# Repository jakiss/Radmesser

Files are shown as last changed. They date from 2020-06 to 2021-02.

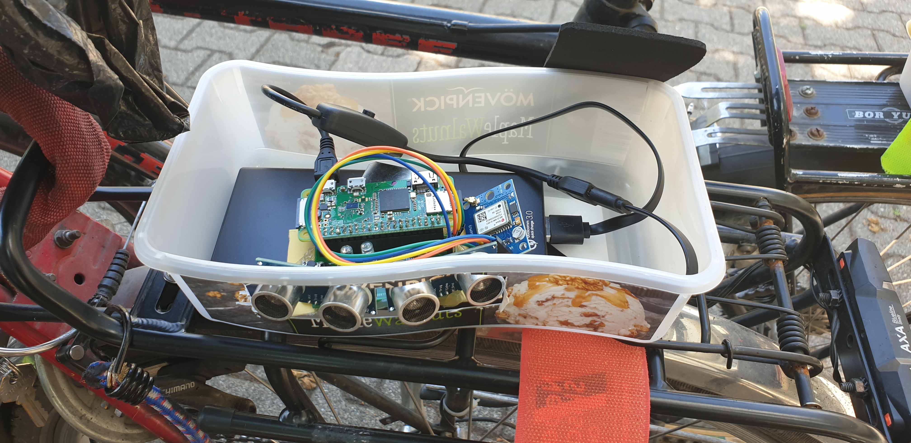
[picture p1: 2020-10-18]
Anleitung_v01_20201018/Bilder/20200816_124822.jpg

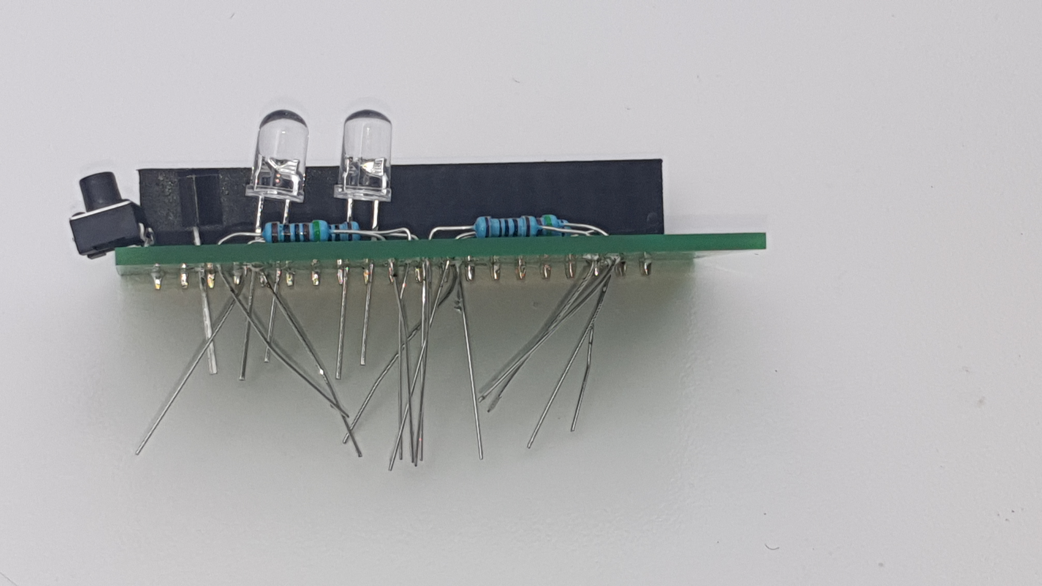
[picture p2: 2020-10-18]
Anleitung_v01_20201018/Bilder/20200725_165101.jpg

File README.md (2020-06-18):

# Radmesser
For the enlish version see below.

Das Projekt befasst sich mit der Entwicklung eines Radmessers nach der Idee des Tagesspiegel Berlin (Vgl. https://interaktiv.tagesspiegel.de/radmesser/ und https://github.com/tagesspiegel/radmesser). 

Die genaue des Beschreibung des Projekts mit Grundidee und Annahmen findet sich unter Projektbeschreibung.pdf, um eine kurze Zusammenfassung zu erhalten empfiehlt sich die Datei Zusammenfassung_Projektbeschreibung.pdf.

Das Projekt darf unter der GNU General Public License (GPL) verwendet werden.

------------------------------------------------------------
English version:

The project deals with the development of a measurement system for the overtaking distance between cars and bicycles after the idea of the Tagesspeigel Berlin (see https://interaktiv.tagesspiegel.de/radmesser/ and https://github.com/tagesspiegel/radmesser).

The detailed description of the project including the main idea and assumptions  can be found in Projektbeschreibung.pdf. For a short summary of the topic the file Zusammenfassung_Projektbeschreibung.pdf is recommended.

The project can be reused under the GNU General Public License (GPL).

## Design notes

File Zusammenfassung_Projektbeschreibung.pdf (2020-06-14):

(T3 3000) – Jahrgang 2017

MESSSYSTEM ZUR BESTIMMUNG VON UBERHOLABST ¨ | ANDEN ¨

## VON KRAFTFAHRZEUGEN GEGENUBER FAHRRADFAHRERN ¨

Jakob Seitzer
Elektrotechnik, TEL17GR5, DHBW Stuttgart
Kurzfassung: Die Arbeit beschaftigt sich mit der Entwicklung eines Messsystems zur Ermittlung der ¨ | Uberhol- ¨
abstande von Kraftfahrzeugen gegen ¨ | uber Fahrradfahrern. Zur Bestimmung der seitlichen Abst ¨ | ande werden Ul- ¨
traschallsensoren (HC-SR04) verwendet, welche an einem Raspberry Pi Zero angebunden sind. Ein Temperatursensor (DS18B20) wird zur Kompensation der Temperaturabhangigkeit der Abstandsmessung verwendet. ¨ Das GPS-Modul GY-GPS6MV2 wird zur Bestimmung von Zeit und Position verwendet. Mit Hilfe einer Auswer-
tungssoftware werden Uberholvorg ¨ | ange aus den aufgezeichneten Daten extrahiert. ¨
Sch ¨usselworter: ¨ | Uberholabstand, Abstandsmessung, Ultraschallsensoren, HC-SR04, GPS-Modul ¨

Abstract: This student research project deals with the construction of a measurement system for recording overtakindg distances between motor wehicels and byciles. For measuring the distance on the left side of the bycile, two ultrasonic ranging sensors (HC-SR04) are used and connected to a Raspberry Pi Zero. A temperature sensor (DS18B20) is used for compensation of tempreature dependency of the distance measurement. The GPS-receiver GY-GPS6MV2 is used for detection of position and time. With a evaluation software the overtaking actions are detectet in the measured data.

Keywords: overtaking distance, distance measurement, ultra sonic raning module, HC-SR04, GPS-receiver

### 1 EINFUHRUNG ¨

Am 28.04.2020 trat die aktuell letzte Anderung der Straßenverkehrsordnung in Kraft. Zentrale Anpassung stellte ¨
hierbei die genaue Festlegung des Mindestuberholabstandes von Kraftfahrzeugen gegen ¨ | uber Fahrradfahrern ¨
dar. Innerorts muss beim Uberholen ein seitlicher Abstand von mindestens ¨ | | | 1,5 m eingehalten werden - außerorts
mindestens 2 m.
In einer groß angelegten Studie des Tagesspiegel Berlin aus dem Jahr 2018, wurde versucht die Uberholabst ¨ | ande ¨
gegenuber Fahrradfahrern in Berlin zu dokumentieren [ ¨ | 1]. Der entwickelte Radmesser ist nicht frei verfugbar. ¨
Aus diesem Grund konnen die Daten nicht unabh ¨ | angig gepr ¨ | uft werden. Es bestehen noch weitere Konzepte ¨
zur Konstruktion eines Radmessers, diese sind jedoch nicht vollstandig funktionsf ¨ | ahig [ ¨ | 2]. Um die Ergebnisse
der Studie des Tagesspiegels zu uberpr ¨ | ufen und auch Daten ¨ | uber andere St ¨ | adte zu erhalten, soll ein offenes ¨
Messsystem zu Erfassung der Uberholabst ¨ | ande entwickelt werden. ¨

### 2 SYSTEMBESCHREIBUNG

Fur das Erfassen der ¨ | Uberholabst ¨ | ande wird ein Messsystem entwickelt werden, welches am Fahrrad montiert ¨
wird und automatisch die Abstande nach links aufzeichnet. Mit Hilfe einer Software werden anschließend die ¨
Uberholabst ¨ | ande aus den gewonnenen Daten extrahiert. ¨

### 2.1 Hardwarekomponenten

Als zentrales Hardwareelement wird eine Recheneinheit benotigt, welche mit den Abstandssensoren kommu- ¨ nizieren kann. Um eine unabhangige und einfache Funktionsweise zu erreichen, wird mit dem Raspberry Pi ¨
Zero gearbeitet. Dieser stellt 40 GPIO-Pins zur Verfugung, an welche Sensoren angeschlossen werden k ¨ | onnen. ¨
Mit der Sprache Python 3 wird eine Software fur das Messsystem auf dem Raspberry Pi entwickelt. Auf der ¨ Micro-SD-Karte des Raspberry Pis werden die gemessenen Daten gespeichert werden.

Um den Uberholabstand zu erfassen werden zwei Ultraschallsensoren verbaut. Als Standardbauteil im unteren ¨
Preissegment fur Abstandssensoren bietet sich der Ultraschallsensor HC-SR04 an. Dieser erfasst zuverl ¨ | assig ¨
einen Messbereich zwischen 4 cm und 5 m und wird in vielen studentischen Projekten verwendet [3] [4]. Die Messung erfolgt nach einem Triggerimpuls von 10 µs. Es werden Schallwellen mit einer Frequenz von 40 kHz
ausgesendet und der Ruckmelde-Pin des Sensors geht auf ¨ | High. Wird der ausgegeben Schall innerhalb von

38 ms wieder empfangen, geht der Ruckmelde-Pin zum Empfangszeitpunkt wieder auf ¨ | Low, ansonsten nach
tmax = 38 ms.

Bei der Verwendung eines Ultraschallsensors muss die Temperaturabhangigkeit der Schallgeschwindigkeit be- ¨
rucksichtigt werden. Im Einsatzbereich des Messsystems ist mit Temperaturen zwischen ¨ | −10 °C und 35 °C, was
eine Abweichung der Schallgeschwindigkeit von bis zu 10 % zur Folge hat. Um die Temperaturabhangigkeit ¨ auszugleichen, wird die Temperatur mit dem Temperatursensor DS18B20 bestimmt. Dieser zeichnet sich durch
einen gunstigen Preis und eine weite Verbreitung in anderen Projekten aus [ ¨ | 5] [6].
Bei dem GPS-Modul, welches fur die Positions- und Zeitbestimmung ben ¨ | otigt wird, gibt es kaum etablierte ¨
Bauteile. Nach ausfuhrlicher Recherche fiel die Entscheidung auf das GPS-Modul NEO-6 der Firma u-blox. F ¨ | ur¨
die vereinfachte Konnektivitat hin zum Raspberry Pi Zero wird das Modul GY-GPS6MV2 verwendet, auf welchem ¨
der Chip NEO-6 verbaut ist. Dieses Modul ist kostengunstig erh ¨ | altlich und kann ¨ | uber die Universal Asynchronous ¨
Receiver Transmitter-Schnittstelle (UART) mit dem Raspberry verbunden werden [7].
Die Uberholvorg ¨ | ange werden durch die unterschiedlichen Zeitpunkte bestimmt, zu welchen das Kraftfahrzeug ¨
von den beiden Ultraschallsensoren erfasst wird. Um eine zeitlich unterschiedliche Erfassung durch die Ultraschallsensoren zu erreichen, mussen diese entweder in einem ausreichenden Abstand voneinander ent- ¨ fernt montiert sein, oder in zwei unterschiedliche Richtungen messen. Zuerst muss in diesem Zusammenhang bestimmt werden, welche maximale Distanz lmax ein Kraftfahrzeug zwischen zwei Messungen der Ul-
traschallsensoren zurucklegt. Innerhalb von St ¨ | adten ist mit einer maximalen Geschwindigkeitsdifferenz von ¨
vmax = 70 km h⁻¹ ≈ 19,44 m s⁻¹ zwischen Radfahrer und Kraftfahrzeug beim Uberholen zu rechnen. ¨
lmax = vmax · tmax = 0,038 ms · 19,44 m s⁻¹ = 0,739 m | (1)
Die Montage der beiden Ultraschallsensoren ist nicht in einem Abstand von 70 cm moglich, da der zur Verf ¨ | ugung ¨
stehende Platz auf dem Fahrrad begrenzt ist. Deshalb mussen die Ultraschallsensoren in zwei unterschiedliche ¨ Richtungen messen. Der minimale Winkel αmin, welchen die Ultraschallsensoren voneinander abgewandt sein
mussen, wird mit Hilfe der berechneten Strecke ¨ | lmax und einer angenommenen Messdistanz von lMess = 1,5 m
bestimmt. Es gilt die Annahme, dass bei α = 0° die Ultraschallsensoren das Kraftfahrzeug zeitgleich erkennen.

αmin = arctan

lmax

lMess

=

0,739 m
1,5 m
= 26,23° | (2)
Es besteht die Moglichkeit entweder einen Ultraschallsensor um mindestens ¨ | αmin = 26,33° vom anderen abzu-
wenden, oder beide um mindestens αmin/2 = 13,17° gegeneinander zu verstellen. Um genauere Messergebnisse zu erzielen, werden beide Ultraschallsensoren um αmin/2 verdreht. Bei dieser Montageart ist der Winkel zwischen Ultraschallsensor und Kraftfahrzeug geringer und die Messabweichung fallt geringer aus. ¨
Alle benotigten Bauteile werden auf eine in KiCad entwickelten Leiterplatte gel ¨ | otet. Dies bietet sowohl die ¨
Moglichkeit einer dauerhaften und sicheren Montage, als auch eine exakte Positionierung der Ultraschallsen- ¨
soren bezuglich des Winkels ¨ | α.

### 2.2 Software f ¨ur das Messsystem

Wie bereits oben beschrieben, kann auf dem Raspberry Pi ein Programm in Python 3 entwickelt werden. Drei zentrale Anforderungen muss das Programm erfullen: ¨

1. Moglichst viele Abstandsmessungen ¨
2. Hohe Ausfallsicherheit
3. Hohe Datensicherheit
Moglichst viele Messungen ¨ | mit den Ultraschallsensoren sorgen fur eine solide Datenlage. Hierf ¨ | ur werden ¨
die beiden Ultraschallsensoren durch den selben Impuls getriggert, sie starten zeitgleich ihre Messungen.
Die Ruckmelde-Pins werden durch die Software ¨ | uberwacht. Sobald einer der beiden Pins auf ¨ | High ist, wird
dieser Zeitpunkt als Startzeitpunkt fur den Ultraschallsensor verwendet. Befinden sich beide R ¨ | uckmelde-Pins ¨
im High-Zustand, wird uberwacht, wie lange sie in diesem Zustand verbleiben. F ¨ | allt ein R ¨ | uckmelde-Pin wie- ¨
der auf Low, ist dessen Messung beendet und die Zeit tMess, kann zusammen mit der Schallgeschwindigkeit cSchall = 340 m s⁻¹ zur Ermittlung der Messdistanz verwendet werden. Unter Berucksichtigung, dass der Schall ¨
in der Zeit tmess sowohl Hin- als Ruckweg zum Kraftfahrzeug zur ¨ | uck gelegt hat, bestimmt sich die Entfernung ¨
des KFZ lMess zu

lMess =

1
- tMess · cSchall | (3)

Sobald beide Ultraschallsensoren ihre Messung beendet haben und das Messergebnis in einer CSV-Datei gespeichert wurde, wird unmittelbar im Anschluss wieder eine neue Messung initiiert. Das Erfassen der Zeit und Postion ist weniger oft notwendig, da zwischen zwei erfassten Positionen interpoliert werden kann, solange diese nicht zu weit voneinander entfernt sind. Als maximaler zeitlicher Abstand tGP Smax ergibt sich aus einem
maximalen raumlichen Abstand, bei welchem noch interpoliert werden kann, von ¨ | lGP Smax = 20 m und einer
maximalen Geschwindigkeit des Fahrradfahrers von vbikemax = 30 km h⁻¹ = 8,33 m s⁻¹
| :

tGP Smax =

lGP Smax

vbikemax

| | = 2,4 s | (4)

Die Temperaturmessung nimmt eine Zeit von bis zu 750 ms in Anspruch [6] und wird deshalb nur in Minuten-
abstanden durchgef ¨ | uhrt. Eine starke Temperaturschwankung ist w ¨ | ahrend einer Fahrradfahrt nicht zu erwarten, ¨
jedoch zwischen verschiedenen Fahrten. Um den Speicherverbrauch moglichst gering zu halten, wird drauf ¨ verzichtet die Postions- und Temperaturdaten zu jedem Messwert der Ultraschallsensoren hinzuzufugen. Diese ¨ werden lediglich einmal als eigene Zeile zum Zeitpunkt der Messung abgelegt.
Ein Eingriff in das Messsystem ist wahrend des Betriebs nicht m ¨ | | oglich und macht deshalb eine ¨ | hohe Ausfallsi-
cherheit erforderlich. Daten mussen zuverl ¨ | assig aufgezeichnet werden. Aus diesem Grund ist ein Stehenbleiben ¨
oder Abbruch des Programms zu verhindern. Durch das sofortige und standige Wiederholen der Messungen ¨ mit den Ultraschallsensoren besteht die Gefahr, dass nicht alle Messungen reibungslos Ablaufen. Wird ein Triggerimpulses nicht korrekt erkannt, wird der normale Messzyklus durchbrochen. Durch Uberwachung der Zeit, ¨
welche das Programm fur eine Abstandsmessung ben ¨ | otigt, wird beim ¨ | Uberschreiten einer Zeitgrenze von ¨ | 50 ms
die Messung beendet. Zudem wird dem Benutzer durch eine Betriebsstatusanzeige bestehend aus zwei LEDs signalisiert, ob ein reibungsloser Programmdurchlauf gewahrleistet ist. Zu Programmstart werden die einzelnen ¨ Komponenten getestet, bevor die Statusanzeige auf betriebsbereit (grune LED) wechselt. Wird ein Sensor als ¨ fehlend oder fehlerhaft erkannt, wird dies dem Nutzer durch eine rote LED signalisiert. Eine Problembehebung muss im Einzelfall erfolgen.

Wahrend einer Messfahrt sind verschiedene Szenarien denkbar, welche zu einem Absturz des Raspberry Pis ¨
fuhren k ¨ | onnen und nicht softwaretechnisch abgefangen werden k ¨ | onnen. Ein Spannungsausfall, entweder durch ¨
eine leere Powerbank oder das Herausrutschen eines Kabels sind ebenso denkbar, wie ein Unfall und eine damit einhergehende Beschadigung des Messsystems bzw. der Recheneinheit. Um die bis zu diesem Zeitpunkt ¨ erfassten Daten nicht zu verlieren, ist eine hohe Datensicherheit erforderlich. In diesem Zusammenhang ist zu berucksichtigen, dass die Datei, welche zum Zeitpunkt des Programmabsturzes beschrieben wird, unbrauchbar ¨ wird und alle darin enthaltenen Daten verloren gehen. Um den Datenverlust zu minimieren, wird nach einer festgelegten Zahl an Messungen (5000) die bisherige Datei geschlossen und eine neue Datei mit fortlaufender Nummerierung erstellt, in welche die neuen Daten gespeichert werden. So gehen maximal 5000 Messwerte verloren, das bedeutet die Messwerte von maximal zwei Minuten.

### 2.3 Auswertungssoftware f ¨ur die Messdaten

Als Auswertungsgrundlage dienen die durch die Messsoftware erstellten CSV-Dateien, welche die gemessenen Abstandswerte, Positionen und Temperaturen beinhalten. Nach dem anfanglichen Einlesen der gemessenen ¨ Daten, welches das Zuweisen der Positions- und Temperaturdaten zu den Abstandsmesswerten beinhaltet, so-
wie die Glattung der gemessenen Abst ¨ | ande, werden diese auf ¨ | Uberholvorg ¨ | ange untersucht. Kennzeichnend ¨
fur¨ Uberholvorg ¨ | ange ist ein Abfallen des Messwerts des hinteren Ultraschallsensors, w ¨ | ahrend der vordere Ul- ¨
traschallsensor weiterhin eine große Distanz erfasst. Danach ermitteln beide Ultraschallsensoren den gleichen kleinen Abstandswert, da sich das Kraftfahrzeug genau neben dem Fahrrad befindet und von beiden Ultraschallsensoren erfasst wird. Zum Ende des Uberholvorgangs steigt der Messwert des hinteren Ultraschallsensors an, ¨ wohingegen der vordere Ultraschallsensor weiterhin das Kraftfahrzeug erfasst und einen kleinen Messwert liefert.
Da jedem Uberholvorgang GPS-Koordinaten zugeordnet sind, ist eine Analyse der ¨ | Uberholvorg ¨ | ange nach Re- ¨
gionen moglich. Um eine exakte regionale Analyse zu erhalten werden die Koordinaten in Adressen bestehend ¨ aus Stadt, Postleitzahl und Straße umgewandelt. Anhand dieser Informationen kann ein Vergleich zwischen
verschiedenen Stadten erfolgen. Innerhalb einzelner St ¨ | adte k ¨ | onnen besonders gef ¨ | ahrliche Straßenabschnitte ¨
erkannt werden. Um die GPS-Koordinaten in Adressen umzuwandeln wird eine Programmierschnittstelle ver-
wendet (Application Programming Interface - API). Aus Kosten- und Kompatibilitatsgr ¨ | unden wird mit der API von ¨
OpencageGeocoder gearbeitet. Nach Ubergabe der Koordinaten wird die dazugeh ¨ | orige Straße gesucht und ¨
die gefundene Adresse mit Informationen uber die Straße (Straßentyp, erlaubte Geschwindigkeit, Anzahl der ¨
Fahrspuren) zuruckgegeben [ ¨ | 8].

### 3 TESTS

### 3.1 Hardwaretests

HC-SR04

la=Messdistanz

lb=seitliche Abweichung

# lc=gemessene Distanz

β

Abbildung 1: Messbereich | der | Ultraschallsensoren
HC-SR04, in Farbe die eingesetzten Objekte

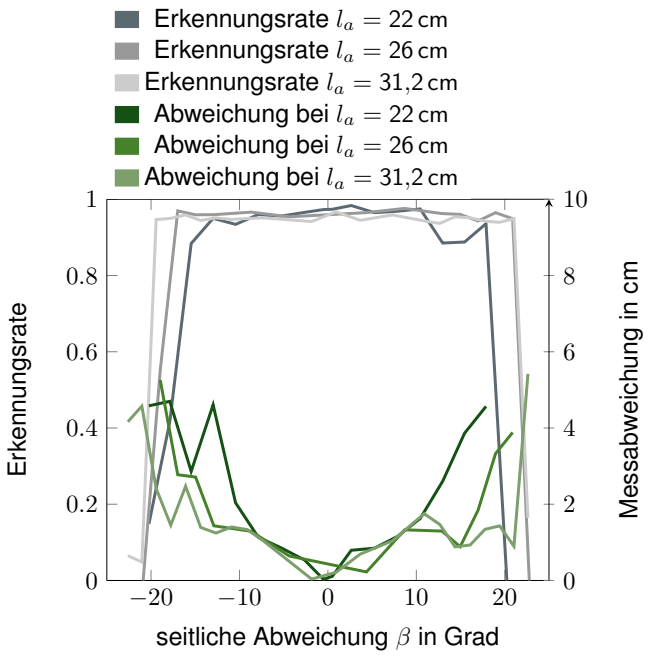
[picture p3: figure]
seitliche Abweichung β in Grad; Erkennungsrate; Messabweichung in cm; Erkennungsrate la = 22 cm Erkennungsrate la = 26 cm Erkennungsrate la = 31,2 cm Abweichung bei la = 22 cm Abweichung bei la = 26 cm Abweichung bei la = 31,2 cm

Abbildung 2: Messbereich der Ultraschallsensoren bei verschiedenen la

Die Ultraschallsensoren mussen hinsichtlich ihres Messbereichs untersucht werden. Durch Tests muss nachge- ¨ wiesen werden, dass die Ultraschallsensoren auch Objekte erfassen, welche nicht senkrecht vor den Ultraschall-
sensoren stehen. In diesem Zusammenhang wird untersucht, inwiefern eine schrage Messfl ¨ | ache (Vgl. Abb. ¨ | 3)
die Messungen beeinflusst und welchen Einfluss ein Abweichen aus der Messsenkrechten (Vgl. Abb. 1) auf die Messergebnisse hat.

In Abb. 1 ist die seitliche Abweichungen eines Objekts von der Messsenkrechten dargestellt. Der Winkel β stellt den Messbereich dar und berechnet sich zu

β = arctan
lb
la
(5)
In Abb. 2 ist die Erkennungsrate in Abhangigkeit der seitlichen Abweichung ¨ | β dargestellt. Die Erkennungsrate ist
definiert als Anteil der Messungen, bei welcher das Objekt erkannt wird. Die Messabweichung ergibt sich aus der
tatsachlich gemessenen Distanz abz ¨ | uglich ¨ | lc. Fur die in Abb. ¨ | 2 dargestellten Punkte, wurden jeweils mindestens
40 000 Messungen durchgefuhrt und per Software ausgewertet. Bei steigender Messdistanz ¨ | la vergroßert sich ¨
der Messbereich β leicht. Zu beobachten ist, dass bis zu einem Winkel β von bis zu 19° ein Objekt zuverlassig ¨ erkannt wird. Die Messabweichung steigt bereits bei β > 16° stark an.
In Abb. 3 ist der Versuchsaufbau fur eine schr ¨ | age Messfl ¨ | ache skizziert. Der Winkel ¨ | γ stellt die Schrage der ¨
Messflache gegen ¨ | uber einer normalen Messfl ¨ | ache, senkrecht zur Messrichtung der Ultraschallsensoren dar. In ¨
Abb. 4 sind die Erkennungsrate und die Messabweichung fur variable Messdistanzen ¨ | la in Abhangigkeit des ¨
Winkels γ dargestellt. Es gelten die selben Definitionen wie oben. Bei steigender Messdistanz la verkleinert sich die Erkennungsrate bei einem Winkel von β ≥ 30° leicht. Die Messabweichung steigt ebenfalls mit zunehmender Schrage ¨ γ der Messflache an. ¨

Das Zunehmen der Messabweichung ist mit dem Erkennungswinkel β der Ultraschallsensoren zu begrunden. ¨
Wird die Messflache mit dem Winkel ¨ | γ schrager aufgestellt, r ¨ | uckt ein Teil der Messfl ¨ | ache innerhalb des Erken- ¨
nungsbereichs naher an den Ultraschallsensor (Vgl. Abb. ¨ | 3, grau gestrichelter Bereich).

HC-SR04

la=Messdistanz

γ

Abbildung 3: Messgenauigkeit bei schragen Fl ¨ | achen, ¨
in Farbe die neuen Messflachen ¨

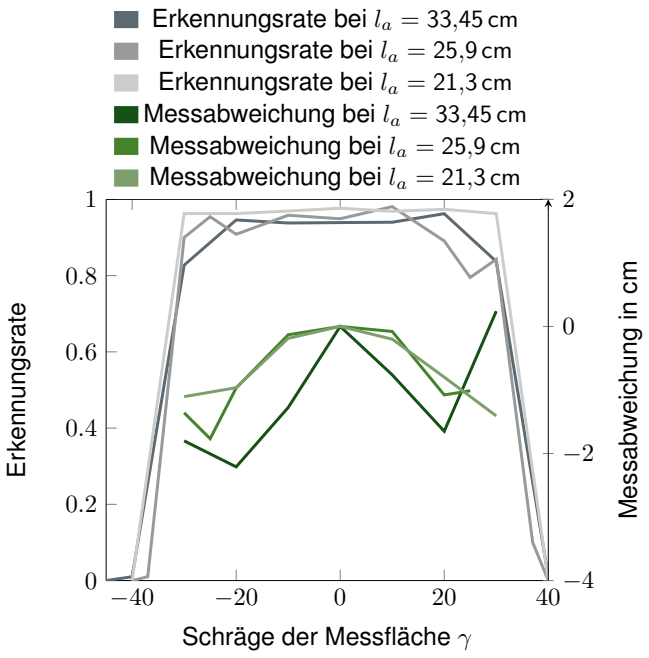
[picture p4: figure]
Schrage der Messfl ¨; ache ¨; Erkennungsrate; Messabweichung in cm; Erkennungsrate bei la = 33,45 cm Erkennungsrate bei la = 25,9 cm Erkennungsrate bei la = 21,3 cm Messabweichung bei la = 33,45 cm Messabweichung bei la = 25,9 cm Messabweichung bei la = 21,3 cm

Abbildung 4: Genauigkeit der Messungen mit Ultraschallsensoren bei schragen Reflexions- ¨ flachen ¨

Es ist festzuhalten, dass die Ultraschallsensoren Objekte erkennen konnen, welche bis zu ¨ | β = 19° aus der
Messsenkrechten abweichen. Die Schrage der Messfl ¨ | ache spielt bei ¨ | γ ≤ 19° eine untergeordnete Rolle. Fur eine ¨
zuverlassige Objekterkennung mit vernachl ¨ | assigbaren Messabweichungen muss der Winkel ¨ | α/2 (Vgl. oben)
kleiner als der Winkel β des Messbereichs sein. Es gilt:

αmax
2
≤ β = 19° | (6)

Bei verschiedenen Tests stellte sich ein Winkel von α/2 = 16° als optimal heraus.

### 3.2 Softwaretest Messsystem

Fur das Messsystem ist ein stabiler Programmablauf sowie das Behandeln von fehlerbehafteten Messwerten ¨
und Sensorausfallen wichtig. Ein Fortlauf des Programms sowie eine nachtr ¨ | agliche Bearbeitungsm ¨ | oglichkeit f ¨ | ur¨
fehlerhafte Messergebnisse stehen im Vordergrund.

In diesem Zusammenhang ist ein Langzeittest erforderlich, um Fehler zu erkennen, welche nicht bereits bei
Programmstart auftreten. Unabhangig der Programmlaufzeit sind keine zus ¨ | atzlichen Fehler aufgetreten. Nach ¨
rund 20 Stunden ist die Powerbank, welche zur Spannungsversorgung verwendet wird, erschopft. ¨

Beim GPS-Modul sind zwei unterschiedliche Fehler moglich. Es kann zu einem kurzfristigen Signalabbruch ¨ kommen oder zu einem dauerhaften Komplettausfall. In beiden Fallen wird der Programmablauf nicht negativ ¨ beeinflusst. Sind die GPS-Daten nur kurzfristig nicht verfugbar, kann zwischen den anderen Koordinaten in- ¨
terpoliert werden. Bei einem dauerhaften Sensorausfall hingegen ist es nicht mehr moglich ¨ | Uberholvorg ¨ | ange ¨
geografisch zu verorten.

Die Ultraschallsensoren konnen verschiedene Fehler aufweisen. Bei einzelnen Messungen kann es zu falschen ¨
Messergebnissen kommen, die Ultraschallsensoren konnen verdeckt oder verschmutzt sein oder sie k ¨ | onnen ¨
komplett ausfallen. Das Programm des Messsystems wird nicht durch falsche Signale der Ultraschallsensoren beeinflusst, da durch einen Zeitabgleich auch ohne Rucksignal der Ultraschallsensoren mit neuen Messungen ¨ fortgefahren wird. Fehlerhafte Messergebnisse, welche außerhalb des Messbereichs der Ultraschallsensoren
liegen konnen durch die Auswertungssoftware aussortiert werden und einzelne abweichende Messwerte k ¨ | onnen ¨
durch die Auswertungssoftware korrigiert werden (Vgl. Glattung). Ein Komplettausfall eines Ultraschallsensors ¨
fuhrt zu einem fatalen Fehler bei der Erkennungssoftware, da diese zur Erkennung von ¨ | Uberholvorg ¨ | angen auf ¨
die unterschiedlichen Messergebnisse der Ultraschallsensoren angewiesen ist.

### 3.3 Softwaretest Auswertungssoftware

Die Auswertungssoftware wird mit gezielt durchgefuhrten ¨ | Uberholvorg ¨ | angen getestet. Die ¨ | Uberholvorg ¨ | ange ¨
wurden mit einem moglichst exakten seitlichen Abstand durchgef ¨ | uhrt, aufgrund von Lenkfehlern von Autofahrer ¨
und Fahrradfahrer, konnte die Distanz jedoch nicht exakt eingehalten werden. Die Auswertungssoftware er-
kannte die Uberholvorg ¨ | ange aus den aufgezeichneten Daten, kleine Abweichungen waren bei der ermittelten ¨
Distanzen zu erkennen. An Stellen ohne Uberholvorg ¨ | ange wurden keine ¨ | Uberholvorg ¨ | ange extrahiert. Die Funk- ¨
tion der Software wurde somit fur beide Richtungen nachgewiesen, korrektes Erkennen aber keine zu große ¨ Sensitivitat. ¨

### 4 FAZIT

Es wurde ein Messsystem zur Erfassung der seitlichen Uberholabst ¨ | ande von Kraftfahrzeugen gegen ¨ | uber Fahr- ¨
radfahrern entwickelt. Uberholvorg ¨ | ange werden durch die Auswertungssoftware automatisch erkannt und regio- ¨
nal verortet. Die Funktion des Messsystems wurde durch mehreren Testreihen nachgewiesen.

Weitere Tests mit verschiedenen Arten von Kraftfahrzeugen sind notwendig, genauso wie das Testen der Aus-
wertungsmoglichkeiten, sobald Daten ¨ | uber viele ¨ | Uberholvorg ¨ | ange vorliegen. ¨

LITERATUR

[1] Tagesspiegel Online. (2018). “radmesser”, Verlag Der Tagesspiegel GmbH, Adresse: https://interaktiv.tagesspiegel.de/radmesser/index.html (https://interaktiv.tagesspiegel.de/radmesser/index.html) (besucht am 12. 12. 2019).
[2] Zweirat Stuttgart. (2020). “Friends of Open Bike Sensor, Citizen Science Project by Zweirat Stuttgart”, Adresse: https://github.com/Friends-of-OpenBikeSensor (besucht am 28. 05. 2020).
[3] K. A. Raza und W. Monnet, “Moving objects detection and direction-finding with HC-SR04 ultrasonic linear array”, in 2019 International Engineering Conference (IEC), 2019, S. 153–158.
[4] D. Vakula und Y. K. Kolli, “Low cost smart parking system for smart cities”, in 2017 International Conference on Intelligent Sustainable Systems (ICISS), 2017, S. 280–284.
[5] W. Jingzhuo und G. Chenglong, “Research on 1-Wire Bus Temperature Monitoring System”, in 2007 8th International Conference on Electronic Measurement and Instruments, 2007, S. 3–722–3–726.
[6] B. Huang, J. Lei und Y. Bo, “The reading data error analysis of 1-wire bus digital temperature sensor DS18B20”, in 2012 Proceedings of International Conference on Modelling, Identification and Control, Wuhan, Hubei, China, Juni 2012, S. 433–436, ISBN: 978-1-4673-1524-1.
[7] H. Fu, G. Xiong, S. Chen, M. Qiu, H. Xiong, Z. Shen, X. Dong, X. Su und X. Guo, “Design of Low-cost Position Differential Positioning System Based on STM32”, in 2018 Chinese Automation Congress (CAC), 2018, S. 1420–1425. DOI: 10.1109/CAC.2018.8623492. (https://doi.org/10.1109/CAC.2018.8623492)
[8] OpenCage GmbH. (2020). “OpenCage Geocoder”, Adresse: https://opencagedata.com/ (besucht am
12. 05. 2020).

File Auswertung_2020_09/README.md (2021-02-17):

Daten von Juli bis September aus der Region Stuttgart

Erste Auswertungen, nach Straßen, erlaubten Geschwindigkeiten...

Durchschnittlicher Überholabstand von 126,5cm zwischen Fahrradfahrer und KFZ

Die Adressauflösung wurde mit Opencage durchgeführt

Aktuellste Datei stell Ueberholvorgaenge_detailliert_2.csv dar. Dort sind neben Landkreisen und Stadtteilen auch die Uhrzeiten und Daten in einem lesbaren Format dargestellt.

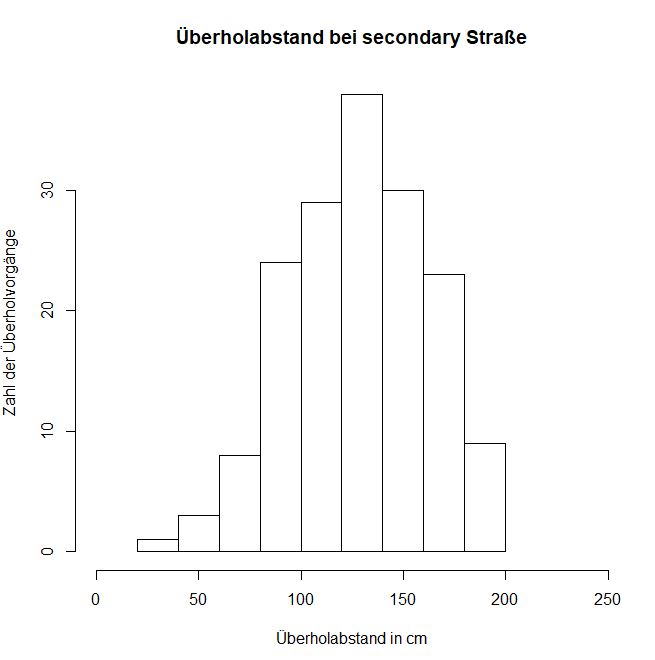
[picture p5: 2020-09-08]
Auswertung_2020_09/Auswertung_anhand_Parameter/Strassen/2_secondary.JPG

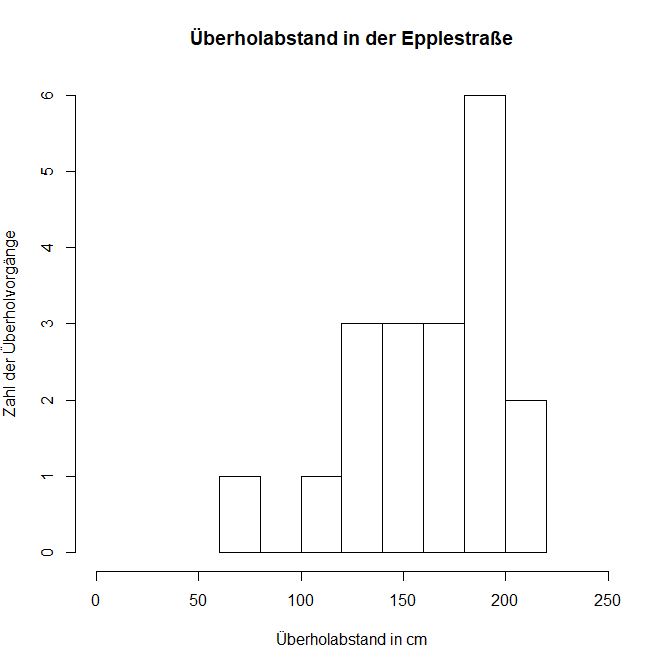
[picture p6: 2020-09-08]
Auswertung_2020_09/Auswertung_anhand_Parameter/Strassen/Epplestr_161cm.JPG

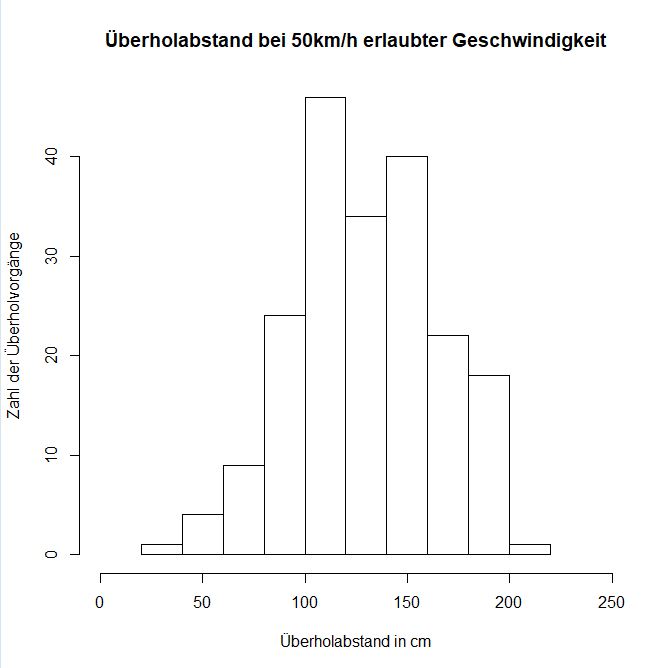
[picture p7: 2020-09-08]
Auswertung_2020_09/Auswertung_anhand_Parameter/bei_50_1_kmh.JPG

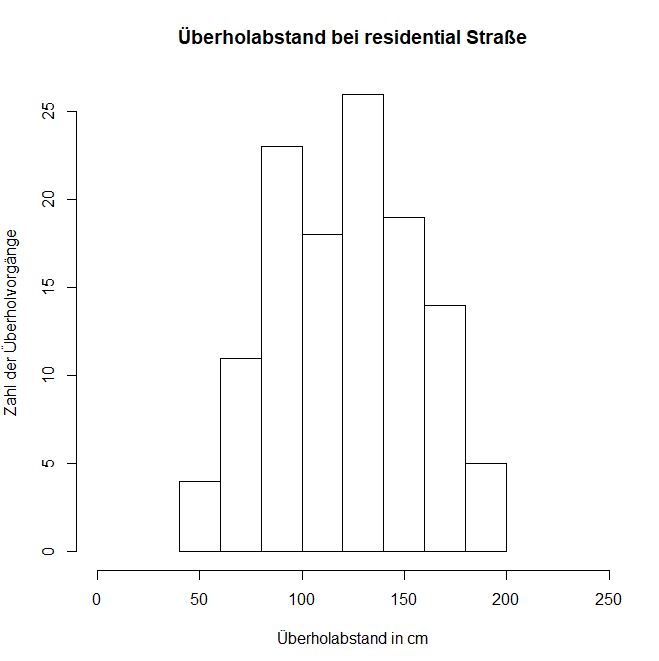
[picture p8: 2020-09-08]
Auswertung_2020_09/Auswertung_anhand_Parameter/Strassen/4_residential.JPG

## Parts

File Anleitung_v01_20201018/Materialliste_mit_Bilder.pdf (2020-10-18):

Materialname | geschätzte Kosten | Stückzahl Beispielbild

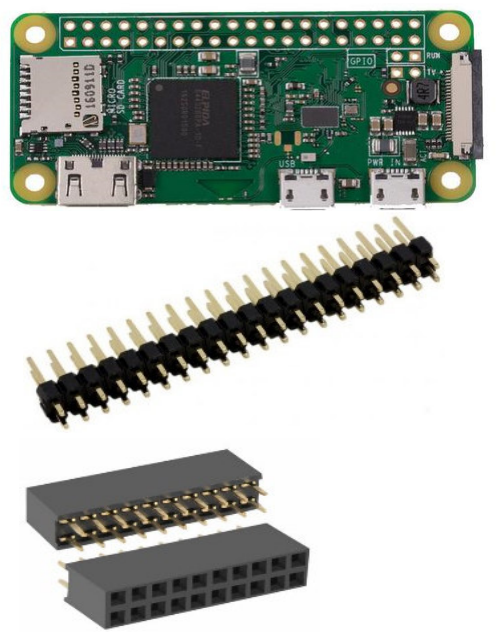
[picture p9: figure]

Raspberry Pi Zero w | 15 € | 1
40 poliger GPIO Header Steckerleiste | 1.00 € | 1
40 poliger GPIO Header Buchsenleiste | 1.00 € | 1
Micro Sd-Karte 16 GB Klasse 10 | 7 € | 1
Powerbank 10 000mAh Intenso (7332530), ansonsten Neuentwicklung des Gehäuses 15 € | 1
Platine selbst entwickelt | 2 € | 1 jlcpcb
Ultraschallsensoren HC-SR04 | 2 € | 2
GPS-Modul NEO-GY-GPS6MV2 | 6 € | 1
4 polige Stiftleiste, 1Reihe | 0.50 € | 1
Temperatursensor 18B20 | 1.00 € | 1
Widerstand 4.7kOhm | 0.02 € | 1
Widerstand 1kOhm | 0.02 € | 2
Widerstand 500Ohm | 0.02 € | 2
Widerstand 100Ohm | 0.02 € | 2
LED low current rot und grün 5mm | 0.02 € | 2
USB-B-Micro USB-A-Kabel mit Schalter | 3 € | 1
Taster (??Kurzhubtaster?) | 1 € | 1
| 55.68 €

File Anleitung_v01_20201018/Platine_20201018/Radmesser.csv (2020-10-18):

ID | Bezeichner | Gehäuse | Stückzahl | Bezeichnung | Anbieter und Referenz
1 | Drot2,Dgrun1 | LED_D5.0mm | 2 | LED
2 | GPS1 | GY-GPS6MV | 1 | GY-GPS6MV2
3 | J1 | PinSocket_2x20_P2.54mm_Vertical | 1 | Raspberry_Pi
4 | R1,R3,R5,R6 | R_Axial_DIN0207_L6.3mm_D2.5mm_P15.24mm_Horizontal | 4 | 1k
5 | R2,R4 | R_Axial_DIN0207_L6.3mm_D2.5mm_P15.24mm_Horizontal | 2 | 470
6 | Uhinten2,Uvorne1 | XCVR_HC-SR04 | 2 | HC-SR04

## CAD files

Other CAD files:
Anleitung_v01_20201018/Auswertungssoftware/Auswertungssoftware_Anleitung_20201018.obj

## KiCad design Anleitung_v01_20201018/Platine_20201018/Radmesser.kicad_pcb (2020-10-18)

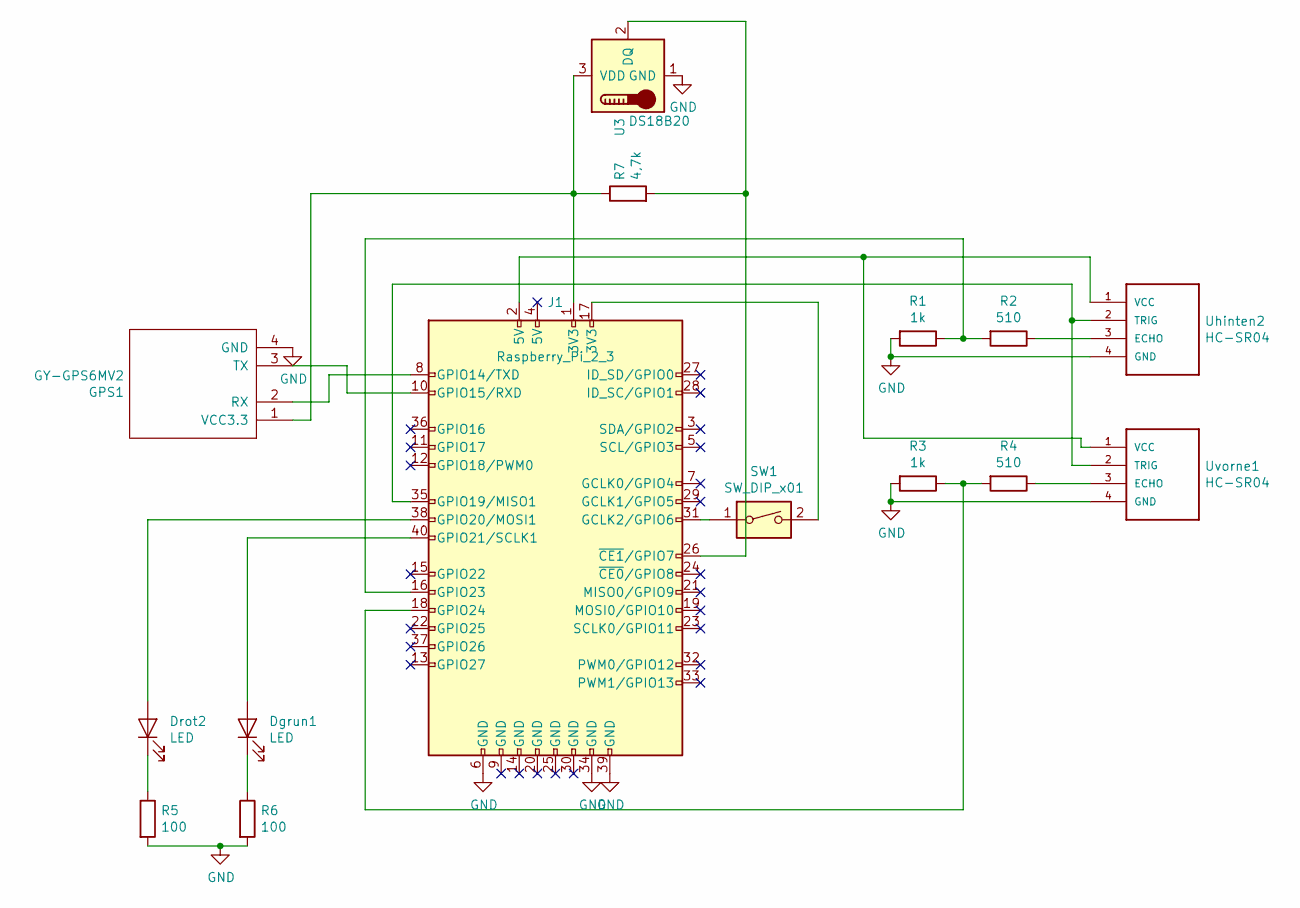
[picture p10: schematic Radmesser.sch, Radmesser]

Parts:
Dgrun1: LED; LED_D5.0mm
Drot2: LED; LED_D5.0mm
GPS1: GY-GPS6MV2; GY-GPS6MV
J1: Raspberry_Pi_2_3; PinSocket_2x20_P2.54mm_Vertical
R1, R3: 1k; R_Axial_DIN0207_L6.3mm_D2.5mm_P15.24mm_Horizontal
R2, R4: 510; R_Axial_DIN0207_L6.3mm_D2.5mm_P15.24mm_Horizontal
R5, R6: 100; R_Axial_DIN0207_L6.3mm_D2.5mm_P15.24mm_Horizontal
R7: 4,7k; R_Axial_DIN0207_L6.3mm_D2.5mm_P15.24mm_Horizontal
SW1: SW_DIP_x01; SW_PUSH_6mm_h5mm
U3: DS18B20; TO-220-3_Vertical
Uhinten2: HC-SR04; XCVR_HC-SR04
Uvorne1: HC-SR04; XCVR_HC-SR04

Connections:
GND: GPS1.4 (GND), J1.6 (GND), J1.34 (GND), J1.39 (GND), R1.2, R3.2, R5.2, R6.2, U3.1 (GND), Uhinten2.4 (GND), Uvorne1.4 (GND)
unnamed: Dgrun1.1 (K), R6.1
unnamed: Dgrun1.2 (A), J1.40 (GPIO21/SCLK1)
unnamed: Drot2.1 (K), R5.1
unnamed: Drot2.2 (A), J1.38 (GPIO20/MOSI1)
unnamed: GPS1.1 (VCC3.3), J1.1 (3V3), R7.1, U3.3 (VDD)
unnamed: GPS1.2 (RX), J1.8 (GPIO14/TXD)
unnamed: GPS1.3 (TX), J1.10 (GPIO15/RXD)
unnamed: J1.2 (5V), Uhinten2.1 (VCC), Uvorne1.1 (VCC)
unnamed: J1.16 (GPIO23), R1.1, R2.2
unnamed: J1.17 (3V3), SW1.2
unnamed: J1.18 (GPIO24), R3.1, R4.2
unnamed: J1.26 (~CE1~/GPIO7), R7.2, U3.2 (DQ)
unnamed: J1.31 (GCLK2/GPIO6), SW1.1
unnamed: J1.35 (GPIO19/MISO1), Uhinten2.2 (TRIG), Uvorne1.2 (TRIG)
unnamed: R2.1, Uhinten2.3 (ECHO)
unnamed: R4.1, Uvorne1.3 (ECHO)

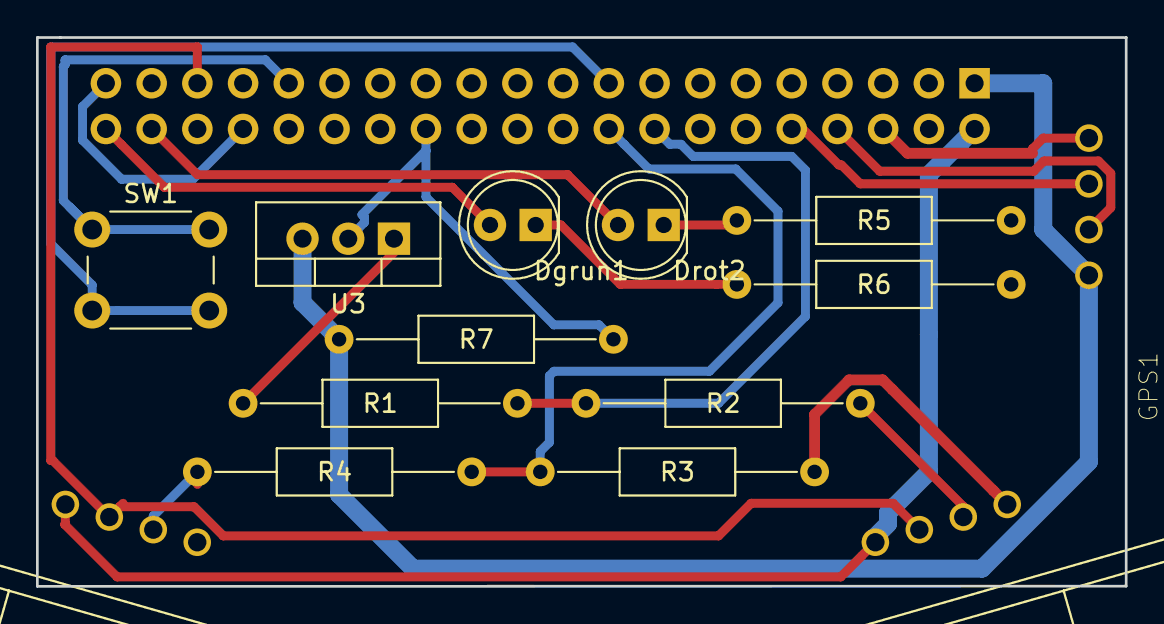
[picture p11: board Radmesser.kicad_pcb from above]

Board: 2 copper layers, 60.5 x 30.5 mm, 15 parts (1 on the bottom side), 17 nets.

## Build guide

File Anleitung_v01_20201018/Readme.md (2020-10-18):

Die ausführliche Anleitung finden Sie in der Datei Anleitung.pdf.
Wir haben derzeit noch ein kleines Problem mit unserem Temperatursensor auf der Softwareseite, werden jedoch versuchen dieses so schnell wie möglich zu beheben und ein aktualisiertes Image zur Verfügung zu stellen.

Für den späteren Betrieb ist es wichtig, dass nach einem anfänglichen Blincken im Gleichtakt der LEDs nur noch die grüne LED leuchtet.
Ist dies nicht der Fall, liegt ein Fehler vor. Die rote LED blinkt immer dann auf, wenn ein falscher Messwert aufgezeichent wurde.

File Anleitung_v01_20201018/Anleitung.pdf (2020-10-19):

## Anleitung Kesselbox

Jakob Seitzer

19. Oktober 2020

## 1 Materialliste

| Raspberry Pi Zero W
| GPIO Steckerleiste (40 polig, 2 Reihen, 20 Pole pro Reihe, 2.54 cm)
| GPIO Buchsenleiste (40 polig, 2 Reihen, 20 Pole pro Reihe, 2.54 cm)
| Micro-SD-Karte (mind. 16 GB, Klasse 10 oder Ultra-High-Speed 1)
| Powerbank (5000 mAh bis 10 000 mAh)
| Ultraschallsensoren HC-SR04 2 Stuck ¨
| GPS-Modul NEO-GY-GPS6MV2 (alternativ kann auch eine bessere Version, 7M oder 8M
eingesetzt werden, Vgl. ebay.de)
| GPIO Steckerleiste (4 polig, 1 Reihe, 4 Pole pro Reihe, 2.54 cm)
| Temperatursensor (DS18B20)
| Widerstand 4.7 kΩ
| Widerstand 1 kΩ 2 Stuck ¨
| Widerstand 510 Ω 2 Stuck ¨
| Widerstand 100 Ω 2 Stuck ¨
| Low-Current-LED grun (5 mm, Nennstrom 2 mA) ¨
| Low-Current-LED rot (5 mm, Nennstrom 2 mA)
| Kurzhubtaster (4 Pin, 6x6x7mm)
| USB-Kabel mit Schalter (USB-B-Micro - USB-A)
| Selbst entwickelte Platine (siehe angehängter Ordner auf Github)

### 1.1 Anmerkungen zu den Materialien

Die Anmerkungen stellen kleine technische Ausfuhrungen dar. Von Laien m ¨ | ussen diese nicht ¨
weiter beachtet werden.

Der Raspberry Pi kann direkt mit der Steckerleiste auf der Platine montiert werden, dies reduziert jedoch die Wiederverwendbarkeit des Raspberry Pis, falls dieser auch in anderen Projekten eingesetzt werden soll

Eine 16 GB-SD-Karte reicht fur rund 1000 Stunden Fahrradfahren bzw. 20 000 km gefah- ¨ rener Strecke. Eine 32 GB-SD-Karte ermöglicht das Speichern der vierfachen Datenmenge (4000 Stunden)

Bisherige Versionen der Kesselbox wurden mit dem NEO-GY-GPS6MV2 ausgestattet. Dieser ist auch unter abweichenden Namen zu finden. Die Version 7M bzw. 8M stellen eine Verbesserung dar, bisher wurde die Kesselbox nur mit dem NEO-GY-GPS6MV2 getestet, ggf. sind mit den anderen GPS-Modulen Anpassungen notwendig.

Die Toleranz der Widerstände ist unerheblich, genauso wie die maximale Leistung. Die Widerstände (1 kΩ und 510 Ω dienen als Spannungsteiler und können proportional nach oben und unten skaliert werden)

| Werden keine Low-Current-LEDs eingesetzt sondern normale LEDs wird eine zu große
Leistung uber die GPIO-Pins des Raspberry Pis bezogen, was zu einer Besch ¨ | ädigung oder
eines kompletten Ausfalls des Raspberry Pis fuhren kann. ¨

Durch die selbst entwickelte Platine wird der genaue Winkel zwischen den Ultraschallsensoren garantiert. Das eigenständige Entwickeln einer Platine ist selbstverständlich auch möglich. Bestellmöglichkeiten sind: https://jlcpcb.com/ oder https://oshpark.com.

## 2 Montage der Bauteile

1. Montage der Widerstände
| Drähte der Widerstände abknicken
| Widerstände auf der Ruckseite anl ¨ | öten (Vgl.: https://www.youtube.com/watch?v=d6e-
| goeZKbA)
| R1 und R3 werden mit den beiden 1 kΩ Widerständen versehen
| R2 und R4 werden mit den beiden 510 Ω-Widerständen versehen
| R7 wird mit dem 4.7 kΩ-Widerstand versehen
| R5 und R6 werden mit den beiden 100 Ω-Widerständen versehen
2. Montage der GPIO-Buchsenleiste (löten)
3. Montage der GPIO-Steckerleiste am Raspberry Pi (löten)
4. Montage der LEDs (ist die Beschriftung richtig herum zu sehen, auf der linken Seite die rote LED montieren)
5. Montage des Schalters
6. Montage des GPS-Moduls
| GPIO-Steckerleiste am GPS-Modul anlöten
| Steckerleiste mit GPS-Modul an Platine löten
| Antenne an GPS-Modul anschließen
7. Temperatursensor anlöten
8. Ultraschallsensoren anlöten
9. Raspberry Pi mit Steckerleiste in Buchsenleiste stecken

### 2.1 Gehäuse

Fur das Geh ¨ | äuse kann entweder ein additiv gefertigtes Gehäuse dienen oder es wird eine beste-
hende Plastikbox verwendet. Wichtig fur den Aufbau ist, dass die Powerbank aus Gr ¨ | unden des ¨
Gleichgewichts und der Stabilität am Boden befestigt wird, dies kann mit doppelseitigem Klebeband erfolgen. Um die Platine stabil und sicher zu montieren, muss diese mit einer planaren Fläche verbunden werden. Am besten wird die Platine mit Heißkleber auf ein kleines Stuck festes ¨ Verpackungsplastik geklebt. Das Plastikstuck mit der Platine kann nun wiederum mit doppel- ¨
seitigem Klebeband befestigt werden. Fur die Ultraschallsensoren sind vier L ¨ | öcher mit einem
Durchmesser von circa 1.6 cm in die Box einzuschneiden. Die Löcher können selbstverständlich auch deutlich größer ausgefuhrt werden. ¨

## 3 Software einrichten

### 3.1 Softwareinstallation auf dem Raspberry Pi

Fur die Installation der Software auf dem Raspberry Pi gibt es zwei M ¨ | öglichkeiten. Die erste ist
auch fur Laien geeignet. Die zweite erfordert zus ¨ | ätzliche Linux- und Softwarekenntnisse.

Image auf die SD-Karte spielen Das Image wird heruntergeladen und entpackt (Link folgt). Das Programm Win32DiskImager wird heruntergeladen und installiert (Chip.de). Die Micro-SD-Karte wird mit einem Micro-SD-Karten-Adapter in einen Laptop eingelegt. Das Programm Win32DiskImager wird gestartet. Als Datenträger wird die eingelegte Micro-SD-Karte ausgewählt und als zugehörige Datei das heruntergeladene Image ausgewählt. Danach wird mit dem ”

Schreiben-Button“ der Schreibvorgang gestartet. Es besteht eine circa 20 minutige War- ¨ tezeit.

Einrichten des Raspbian-Betriebssystems - fur Fachfrauen und Fachm ¨ | änner Es wird
eine Micro-SD-Karte mit einem bestehenden Raspbian-Betriebssystem vorausgesetzt. Darauf aufbauend werden die folgenden Einstellungen beschrieben. Es wird der Quellcode von Github heruntergeladen und auf dem Raspberry Pi gespeichert. Die Datei /etc/rc.local wird mit der Zeile python3/Dateispeicherort/Dateiname ergänzt. Dies sorgt fur einen automatischen Start des ¨ Programms direkt nach dem Hochfahren. In den Einstellungen mussen noch die entsprechenden ¨ Schnittstelle I2C und W-1 freigegeben werden. Zudem muss das Paket xrdp installiert werden, ggf. sind weitere Pakete zu installieren.

## 4 Allgemeiner Betrieb

Nachdem die Micro-SD-Karte, wie oben beschrieben eingerichtet wurde, wird der Raspberry Pi uber das Ein- und Ausschalten der Spannung bedient. Vor Fahrtbeginn wird die Spannung ¨
eingeschaltet. Nach ein paar Sekunden beginnen die rote und grune LED f ¨ | ur rund 30 Sekunden ¨
im Gleichtakt zu blinken. Danach ist die Kesselbox einsatzbereit. Die Kesselbox funktioniert ohne weiteres Zutun. Nach dem Ende der Fahrt wird die Spannung abgeschaltet. Vor der nächsten Fahrt muss dann lediglich wieder die Spannung eingeschaltet.

## 5 Daten von der Kesselbox abrufen

Um die gesammelten Daten von der Kesselbox auszuwerten und zusammenzutragen mussen ¨ diese vom Raspberry Pi abgerufen werden.

### 5.1 Ersteinrichtung

Zum Abrufen der Daten wird eine Remote-Desktop-Verbindung verwendet, auf dem Raspberry
Pi muss dafur die xrdp-Bibliothek installiert sein. F ¨ | ur eine RDP-Verbindung muss die Kessel- ¨
box mit dem selben WLAN-Netzwerk verbunden sein, wie der Laptop/Computer, auf welchen die Daten ubertragen werden sollen. Es empfiehlt sich beim Einsatz eines Laptops den mobilen ¨ Hotspot des Laptops zu nutzen. Der Raspberry Pi wird mit Hilfe eines Micro-HDMI-Adapters an einen Bildschirm angeschlossen und eine Tastatur und Maus werden uber eine OTG-USB- ¨ Schnittstelle angeschlossen. Im rechten oberen Bildbereich wird das Verbindungssymbol ausgewählt und dann das entsprechende WLAN-Passwort eingegeben. Danach ist die Einrichtung erfolgreich abgeschlossen. In Zukunft reicht es aus, vom Laptop aus uber das entsprechendee ¨ WLAN-Netzwerk und RDP auf den Raspberry Pi zuzugreifen. Die Anmeldedaten lauten: Benutzernamen: root, Passwort: juergenjuergen

### 5.2 Weitere Daten abrufen

Das WLAN wird eingeschaltet, der Raspberry Pi eingeschaltet und gewartet, bis dieser sich mit dem WLAN verbindet. Die Verbindung kann gepruft werden, wenn man sich auf dem WLAN- ¨ Router einloggt oder die WLAN-Einstellungen am Laptop betrachtet. In der Windowssuchleiste wird nach Remotedesktopverbindung gesucht. In der Zeile Computername der RDP-Verbindung wird nach raspberrypi gesucht. Unter dem Reiter Lokale Ressourcen wird im Bereich Lokale Geräte und Ressourcen die Zwischenablage angewählt, sowie unter Weitere, die entsprechenden Laufwerke ausgewählt. Mit Verbinden wird die Verbindung initiiert. Es dauert nun einige Sekunden, danach erscheint ein blauer Bildschirm mit einer Anmeldemaske. In der obersten Zeile muss Xorg ausgewählt werden. Die Anmeldung erfolgt mit dem bekannten Nutzernamen und Passwort (Vgl. oben). Die Dateien befinden sich in der obersten Ordnerebene. Die Dateien werden nun kopiert und in einem Ordner auf dem Laptop abgelegt. Die auf dem Raspberry Pi beste-
henden Dokumente werden gelöscht, um Platz fur neue Daten zu machen. Insgesamt k ¨ | önnen
Daten bis zu 1000 Stunden Fahrzeit gespeichert werden. Je nach Geschwindigkeit, können somit
20 000 km zuruckgelegt werden, bis der Speicherplatz ersch ¨ | öpft ist. Die Dateien können ent-
weder selbst ausgewertet werden. Es steht ein Auswertungsprogramm zur Verfugung, welches ¨ einfach in das Verzeichnis eingefugt, in welchem die aufgezeichneten Dateien abliegen. Alternativ ¨
können Dateien, sofern uber 500 km zur ¨ | uckgelegt wurden oder drei Monate mit der Kesselbox ¨
gefahren wurde an unsere E-Mail geschickt werden. Wir kummern uns in diesem Fall gerne um ¨ die Auswertung. Um selber zu prufen, ob die Daten korrekt sind, empfiehlt es sich die Dateien ¨ mit den Namen messdatenX.txt anzuschauen, diese sind auf dem Raspberry Pi auf der obersten Ordnerebene. Diese sollten in der ersten Zeile eine Zahl enthalten (Zeit seit Systemstart) in der zweiten und dritten Zeile einen Abstandswert in Zentimeter (zwischen 5 und 12000) und in unregelmäßigen Abständen eine Zeile, welche mit GPRMC beginnt und danach mehrere Zahlen liefert. Einige beispielhafte Datensätze haben wir zu dieser Anleitung abgelegt.

### 5.3 Daten auswerten

Alle abgerufenen Dateien werden in einen gemeinsamen Ordner kopiert. Wichtig ist, dass diese mit aufsteigender Nummer, begonnen mit messdatenX.txt aufgefuhrt sind. In den Ordner wird ¨ das Auswertungsprogramm eingefugt und mit einem Doppelklick gestartet. Mit Hilfe des DMD- ¨ Compilers kann auch der Quellcode selbst kompiliert werden. In der Datei erkannte.csv sind alle
erkannten Uberholvorg ¨ | änge abgelegt, mit dem Abstand, den entsprechenden Koordinaten usw.
Diese Datei können Sie uns gerne per Mail ubermitteln, alsbald Sie ¨ | uber 500 km zur ¨ | uckgelegt ¨
haben oder uber drei Monate mit der Kesselbox unterwegs waren. ¨

## 6 Daten sammeln

Wir sind ein studentisches Projektteam, das sich mit den Uberholabst ¨ | änden von KFZ gegenuber ¨
Fahrradfahrern beschäftigt. Um ein möglichst umfängliches Bild zu bekommen, versuchen wir möglichst viele Daten zu sammeln. Deshalb veröffentlichen wir den Bauplan unserer Kesselbox. Zentrum der Messung soll zwar die Stuttgarter Innenstadt sein, jedoch sind wir auch aus Daten uberall sonst aus der Bundesrepublik oder der ganzen Welt interessiert. Wir stellen hierbei gerne ¨
die Schnittstelle fur das Sammeln der Daten zur Verf ¨ | ugung und ver ¨ | öffentlichen die zusammen
getragenen Daten. Je mehr Daten, desto besser ist das Gesamtbild und desto bessere Ruck- ¨
schlusse auf dringend notwendige Radwege k ¨ | önnen gezogen werden. Werden auch Sie ein Teil
des Kesselnetzes, indem Sie eine Kesselbox nachbauen.
Wir bemuhen uns Ihnen m ¨ | öglichst bald ein Video zur Anleitung zur Verfugung zu stellen. ¨

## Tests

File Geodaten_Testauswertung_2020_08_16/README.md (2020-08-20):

Am Sonntag den 16. August 2020 haben wir vom Kesselnetz mit unseren ersten Radmesser-Prototypen eine gemeinsame Testfahrt in Stuttgart durchgeführt.
Die aufgezeichneten Überholvorgänge sind in diesem Ordner abgelegt.

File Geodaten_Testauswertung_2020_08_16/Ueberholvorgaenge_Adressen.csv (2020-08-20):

 | Number | Distance | LAT | LON | speed | date | time | country | state | citytown | postcode | roadname | roadtype | oneway | maxspeed | speedin | lanes | bikespeed
1 | 1 | 191.046 | 48.7829 | 9.17335 | 0 | 160820 | 90949 | Deutschland | Baden-Württemberg | Stuttgart | 70174 | Kriegsbergstraße | secondary | yes | 40 | km/h | 2 | 19.0088
2 | 2 | 206.58 | 48.7829 | 9.17335 | 0 | 160820 | 90949 | Deutschland | Baden-Württemberg | Stuttgart | 70174 | Kriegsbergstraße | secondary | yes | 40 | km/h | 2 | 19.0088
3 | 3 | 106.421 | 48.7832 | 9.16611 | 0 | 160820 | 91159 | Deutschland | Baden-Württemberg | Stuttgart | 70174 | Hegelstraße | tertiary | NA | 40 | km/h | NA | 0.314838
4 | 4 | 222.752 | 48.7829 | 9.16623 | 0 | 160820 | 91426 | Deutschland | Baden-Württemberg | Stuttgart | 70174 | Hoppenlaustraße | residential | yes | 30 | km/h | NA | 8.64509
5 | 5 | 177.499 | 48.7722 | 9.16523 | 0 | 160820 | 93911 | Deutschland | Baden-Württemberg | Stuttgart | 70178 | Hermannstraße | residential | yes | 30 | km/h | NA | 13.6732
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

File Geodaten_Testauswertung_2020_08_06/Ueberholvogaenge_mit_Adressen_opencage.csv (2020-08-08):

 | Number | Distance | LAT | LON | speed | date | time | country | state | citytown | postcode | roadname | roadtype | oneway | maxspeed | speedin | lanes | bikespeed
1 | 1 | 180.26 | 48.7349 | 9.12252 | 0 | 290620 | 173648 | Deutschland | Baden-Württemberg | Stuttgart | 70563 | Böblinger Straße | secondary | yes | 50 | km/h | 1 | 17.0402
2 | 2 | 150.806 | 48.7333 | 9.12759 | 0 | 290620 | 173941 | Deutschland | Baden-Württemberg | Stuttgart | 70563 | Nord-Süd-Straße | secondary | no | 50 | km/h | 2 | 21.2942
3 | 3 | 109.775 | 48.6907 | 9.15352 | 0 | 290620 | 175719 | Deutschland | Baden-Württemberg | Leinfelden-Echterdingen | 70771 | Max-Lang-Straße | secondary | yes | 50 | km/h | 1 | 3.50396
4 | 4 | 155.715 | 48.7413 | 9.1662 | 0 | 300620 | 72253 | Deutschland | Baden-Württemberg | Stuttgart | 70597 | Sigmaringer Straße | tertiary | NA | 50 | km/h | 3 | 1.6742
5 | 5 | 197.071 | 48.7458 | 9.16933 | 0 | 300620 | 72452 | Deutschland | Baden-Württemberg | Stuttgart | 70597 | Epplestraße | tertiary | NA | 50 | km/h | 1 | 12.3731
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

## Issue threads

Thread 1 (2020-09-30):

Bestes Vorgehen zum Nachbauen?

UweKeim, 2020-09-30:
Habe Deine zwei PDFs überflogen, weil bei uns in Eislingen einer der Grünen vorgeschlagen hat, das nachzubauen.

Was wäre denn ein empfehlenswertes Vorgehen beim Nachbauen der HW und Verwenden der SW?

jakiss, 2020-10-01:
Das kommt zentral auf die Vorkentnisse an.

Vorkentnisse im Löten sind für die Montage sinnvoll.

Die Software kann auf zwei verschiedenen Weisen installiert werden, entweder kann ein Raspbian System manuell aufgesetzt werden und danach die Software der Code auf das System übertragen werden oder ein fertiges Images, welches ich gerne zur Verfügung,  kann auf die SD-Karte gespielt werden. Bei einem manuellen Aufsetzten sind Vorkenntnisse mit einem Raspberry Pi oder anderen Linux basierten Systemen erfoderlich.

Die Hardwareliste ist unter https://github.com/jakiss/Radmesser/blob/master/Projektbeschreibung.pdf auf den Seiten 85 (xvi) f. zu finden.

Danach wird noch die entsprechende Platine benötigt, wofür ich zeitnah die verbesserten Dateien zur Verfügung stellen werde. Diese sollte dann gefertigt werden beispielsweise bei https://jlcpcb.com/

Nach der Montage findet dann die Inbetriebnahme des Raspberry Pis statt.

Die einzelnen Schritte sind dann ab Seite 88 (xix) zu finden.

Wie viele Sensoren sollen nachgebaut werden?

Für individuelle Unterstützung stehe ich zur Verfügung. Bei Rückfragen bitte melden.

Gesendet: Mittwoch, 30. September 2020 um 17:36 Uhr
Von: "Uwe Keim" <notifications@github.com>
An: "jakiss/Radmesser" <Radmesser@noreply.github.com>
Cc: "Subscribed" <subscribed@noreply.github.com>
Betreff: [jakiss/Radmesser] Bestes Vorgehen zum Nachbauen? (#1)

Habe Deine zwei PDFs überflogen, weil bei uns in Eislingen einer der Grünen vorgeschlagen hat, das nachzubauen.

Was wäre denn ein empfehlenswertes Vorgehen beim Nachbauen der HW und Verwenden der SW?

—
You are receiving this because you are subscribed to this thread.
Reply to this email directly, view it on GitHub, or unsubscribe.

UweKeim, 2020-10-02:
Danke Dir, @jakiss für Deine ausführlichen Erklärungen.

Habe Elektrotechnik in Esslingen studiert (auch wenn das schon 20 Jahre her ist) und bin selbst Softwareentwickler.

Ich denke, ich komme damit insgesamt schon klar.

Wir wollen das wohl im neuen Jahr mal angehen, da werde ich mich tiefer reingraben und mal schauen wie weit ich komme.

In jedem Fall ein super Projekt von Dir. Hätten wir in Deutschland keine https://mordstreifen.de sondern echte _Protected Bike Lanes_, wäre das natürlich um Welten besser, aber das ist ein ganz anderes, politisches Thema.

Closed 2020-10-21.

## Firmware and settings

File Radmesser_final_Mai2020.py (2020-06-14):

import RPi.GPIO as GPIO
import time
import os
import serial
import pynmea2
import string
import glob

# Temperatursensor erkennen und ansprechen, ist er nicht da
# -> keine Startroutine
base_dir='/sys/bus/w1/devices/'
device_folder = glob.glob(base_dir + '28*')[0]
print(device_folder)
device_file=device_folder+'/w1_slave'

# Das erste Mal die serielle Schnittstelle abfragen
# Startzeit rund 17 Sekunden laut Datenblatt
serialPort = serial.Serial("/dev/ttyS0", 9600, timeout=2)

# File-Pointer definieren
file=open('testmessung00.txt', 'w')
f=file
j=0
test="messdaten"
# bis eine neue Datei geschrieben werden kann
x=0
while(os.path.exists("{0}{1}.txt".format(test, x))):
    x=x+1
#V oreinstellungen
GPIO.setmode(GPIO.BCM)
GPIO.setwarnings(False)
# Variabeln definieren
PIN_TRIGGER=19
PIN_ECHOVorne=24
PIN_ECHOHinten=23
PIN_RICHTIG=21
PIN_FALSCH=20
PIN_DOWN=6
# PINs korrekt belegen
GPIO.setup(PIN_TRIGGER, GPIO.OUT)
GPIO.setup(PIN_ECHOVorne, GPIO.IN)
GPIO.setup(PIN_ECHOHinten, GPIO.IN)
GPIO.setup(PIN_RICHTIG, GPIO.OUT)
GPIO.setup(PIN_FALSCH, GPIO.OUT)
GPIO.setup(PIN_DOWN, GPIO.IN)
# Zu Beginn die OUTPUTs einstellen
GPIO.output(PIN_FALSCH, GPIO.HIGH)
GPIO.output(PIN_RICHTIG, GPIO.LOW)
GPIO.output(PIN_TRIGGER, GPIO.LOW)
time.sleep(0.5)
begin=time.time()
# Definition des Exit-Falls
def shutdown(channel):
    f.close()
    os.system("sudo shutdown -h now")
# Definition des Exit-Events
GPIO.add_event_detect(PIN_DOWN, GPIO.FALLING,callback=shutdown)
# Unterprogramm: ruft den Temperatursensor auf
def read_temp_raw():
    ft=open(device_file,'r')
    lines=ft.readlines()
    ft.close()
    return lines
# Unterprogramm wandelt Rueckmeldung des Temperatursensors in lesbares Format
def read_temp():
    lines=read_temp_raw()
    while (lines[0].strip()[-3:]!='YES'):
        time.sleep(0.2)
        lines=read_temp_raw()
    equals_pos=lines[1].find('t=')
    if(equals_pos!=-1):
        temp_string=lines[1][equals_pos+2:]
        temp_c=float(temp_string)/1000.0
	# Temperatur wird um den Faktor 1000 zu gross 
	# -> siehe Datenblatt DS18B20
    return temp_c
#Unterprogramm um beide Ultraschallsensoren gleichzeitig verwenden zu konnen
def UP():
    #Trigger-Impuls fur beide Ultraschallsensoren setzen
    GPIO.output(PIN_TRIGGER, GPIO.HIGH)
    time.sleep(0.00001)
    GPIO.output(PIN_TRIGGER, GPIO.LOW)
    #Zeitvariablen definieren
    t_begin=time.time()
    t_start=time.time()
    t_endvorne=t_start
    t_endhinten=t_start
    #Warten bis beide Echo-Pins 1 sind
    while((GPIO.input(PIN_ECHOVorne)==0)|(GPIO.input(PIN_ECHOHinten)==0)):
        t_start=time.time()
        #nach Zeituberschreitung (100ms) Schleife verlassen
        if(t_start-t_begin>0.1):
            break
    #Warten bis beide wieder Rucksignal bekommen haben
    while((GPIO.input(PIN_ECHOVorne)==1)|(GPIO.input(PIN_ECHOHinten)==1)):
        if(GPIO.input(PIN_ECHOVorne)==1):
            t_endvorne=time.time()
        if(GPIO.input(PIN_ECHOHinten)==1):
            t_endhinten=time.time()
    #Zeitdifferenz berechnen
    t_diffvorne=t_endvorne-t_start
    t_diffhinten=t_endhinten-t_start
    #Strecke berechnen mit v=342m/s
    wayvorne=t_diffvorne*17150
    wayhinten=t_diffhinten*17150
    #Allgemeine Zeit berechnen
    t_gesamt=t_start-begin
    #In Datei schreiben
    f.write("%1.3f,"%t_gesamt)
    f.write("%2.1f,"%wayvorne)
    f.write("%2.1f,"%wayhinten)
    f.write("\n")
    #LEDs zur Statusanzeige ansteuern
    if((wayvorne<5)|(wayvorne>2000)|(wayhinten>2000)|(wayhinten<5)):
        GPIO.output(PIN_FALSCH, GPIO.HIGH)
    else:
        GPIO.output(PIN_FALSCH, GPIO.LOW)
    return 0

#Startroutine, Ultraschallsensoren werden auf Funktion getestet
GPIO.output(PIN_FALSCH, GPIO.HIGH)
messwert=0
while((messwert<10)|(messwert>500)):
    GPIO.output(PIN_TRIGGER, GPIO.HIGH)
    time.sleep(0.00001)
    GPIO.output(PIN_TRIGGER, GPIO.LOW)
    t_startup=time.time()
    t_endup=t_startup
    while(GPIO.input(PIN_ECHOVorne)==0):
        t_startup=time.time()
    while(GPIO.input(PIN_ECHOVorne)==1):
        t_endup=time.time()
    t_diffup=t_endup-t_startup
    messwert=t_diffup*17150
messwert=0
while((messwert<10)|(messwert>500)):
    GPIO.output(PIN_TRIGGER, GPIO.HIGH)
    time.sleep(0.00001)
    GPIO.output(PIN_TRIGGER, GPIO.LOW)
    t_startup=time.time()
    t_endup=t_startup
    while(GPIO.input(PIN_ECHOHinten)==0):
        t_startup=time.time()
    while(GPIO.input(PIN_ECHOHinten)==1):
        t_endup=time.time()
    t_diffup=t_endup-t_startup
    messwert=t_diffup*17150
#Test der Ultraschallsensoren erfolgreich abgeschlossen
GPIO.output(PIN_FALSCH, GPIO.LOW)
#Das GPS-Modul wird im Folgenden hoch gefahren
z=0
while(z<30):
    serialPort = serial.Serial("/dev/ttyS0", 9600, timeout=2)
    GPIO.output(PIN_RICHTIG, GPIO.HIGH)
    GPIO.output(PIN_FALSCH, GPIO.HIGH)
    time.sleep(0.5)
    GPIO.output(PIN_RICHTIG, GPIO.LOW)
    GPIO.output(PIN_FALSCH, GPIO.LOW)
    time.sleep(0.5)
    z=z+1
GPIO.output(PIN_RICHTIG, GPIO.HIGH)
GPIO.output(PIN_FALSCH, GPIO.LOW)
#an dieser Stelle ist noch ein Test des GPS-Moduls sinnvoll
while True:
    messzahl=0#Zahler fur Messungen
    file=open("{0}{1}.txt".format(test, x), 'w')
    # Datei mit entsprechender Nummer offnen
    f=file
    # verkuerzter Filepointer
    temp_c=read_temp()
    # Temperaturabfrage und in Datei schreiben
    f.write("Temperatur,")
    f.write("%f"%temp_c)
    f.write("\n")
    while(messzahl<5000):
    # 5000Messungen in einer Datei
        if((messzahl%100)==0):
	# alle 100 Messwerte wird GPS-Position hinzugefugt, ca. alle 2,5 Sekunden
            serialPort = serial.Serial("/dev/ttyS0", 9600, timeout=2)
	    # neue GPS-Position abfragen
            str =serialPort.readline()
	    # Ubermitteltes Protokoll lesen
            f.write(str.decode())
	    # in Datei schreiben, encode -> Schnittstelle liefert Bytes 
        UP()#Messung durchfuhren
        messzahl=messzahl+1#Zahler fur Messungen hochzahlen
    x=x+1#Zahler fur nachste Datei
    f.close()#alte Datei schliessen
    if(x>25000):
    #wenn mehr als 25000 Dateien erstellt wurden gibt es einen Alarm
        GPIO.output(PIN_RICHTIG, GPIO.LOW)
        GPIO.output(PIN_FALSCH, GPIO.HIGH)
    else:
        GPIO.output(PIN_RICHTIG, GPIO.HIGH)

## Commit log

2020-06-14 Script for the Raspberry Pi Zero
2020-08-20 Ergebnisse Testfahrt 2020-08-16
    [Ueberholvorgaenge_Adressen.csv]
2020-09-08 added new evaluation
    [Ueberholvorgaenge.csv]
2020-10-18 Anleitung added for interests
    [Radmesser-B.Cu.gbr, Radmesser-B.Mask.gbr, Radmesser-B.Paste.gbr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]
2020-11-05 Kommentierter Quellcode und unnötiges entfernt
    [Auswertungssoftware_Anleitung_20201018.obj]
